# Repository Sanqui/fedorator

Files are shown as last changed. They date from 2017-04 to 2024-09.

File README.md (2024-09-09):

Fedorator
===

This is a repo containing source files for the Fedorator.

The Fedorator is a device for writing a live image of
[Fedora](http://fedoraproject.org/), the Linux distribution, onto a USB
flash drive.  It acts as a multimedia hub on Fedora booths at tech conferences
and trade shows.

**Fedorator is no longer maintained.**  If you're looking for a similar project, check out [SyncStar](https://github.com/gridhead/syncstar/)!

Mailing List
---

There is a mailing list about Fedorator: [fedorator@lists.fedoraproject.org](https://lists.fedoraproject.org/admin/lists/fedorator.lists.fedoraproject.org/)

Flock 2017 Version
---

This is the version that was built at Flock 2017.

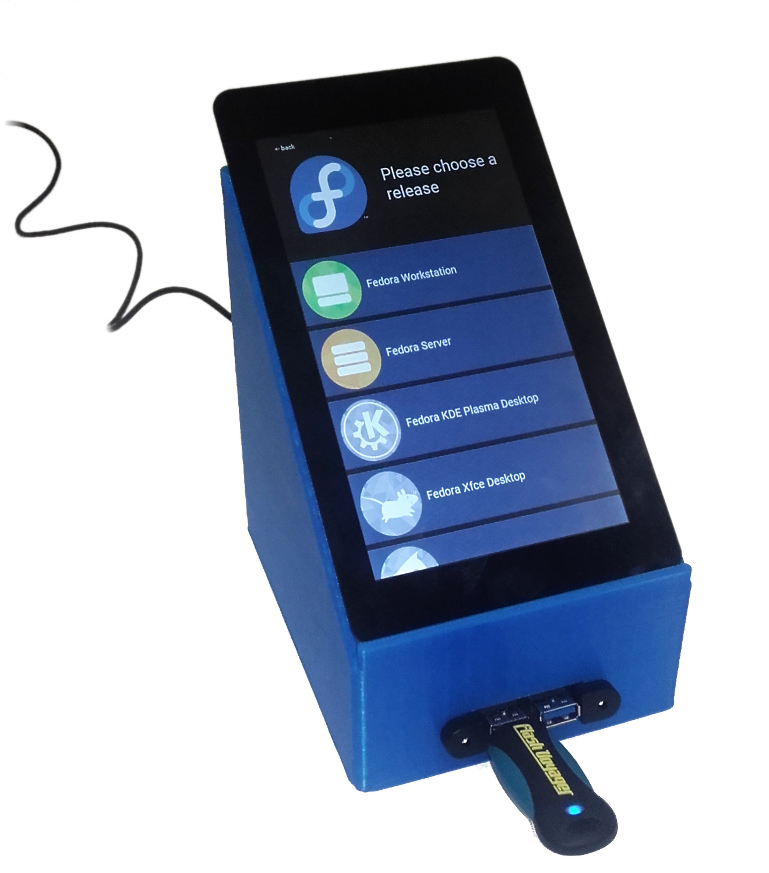
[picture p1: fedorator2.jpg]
Fedorator 2


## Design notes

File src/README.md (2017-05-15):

The fedorator source code, written in Python 3 with the Kivy framework.

The Fedora release information in data/ and img/ comes from
[Fedora Media Writer](https://github.com/MartinBriza/MediaWriter/tree/master/app/assets).

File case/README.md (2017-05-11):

`raspberry_pi_Bplus.STL` is by elsondesigns, lincensed as CC BY-SA.

Source: https://www.thingiverse.com/thing:412639

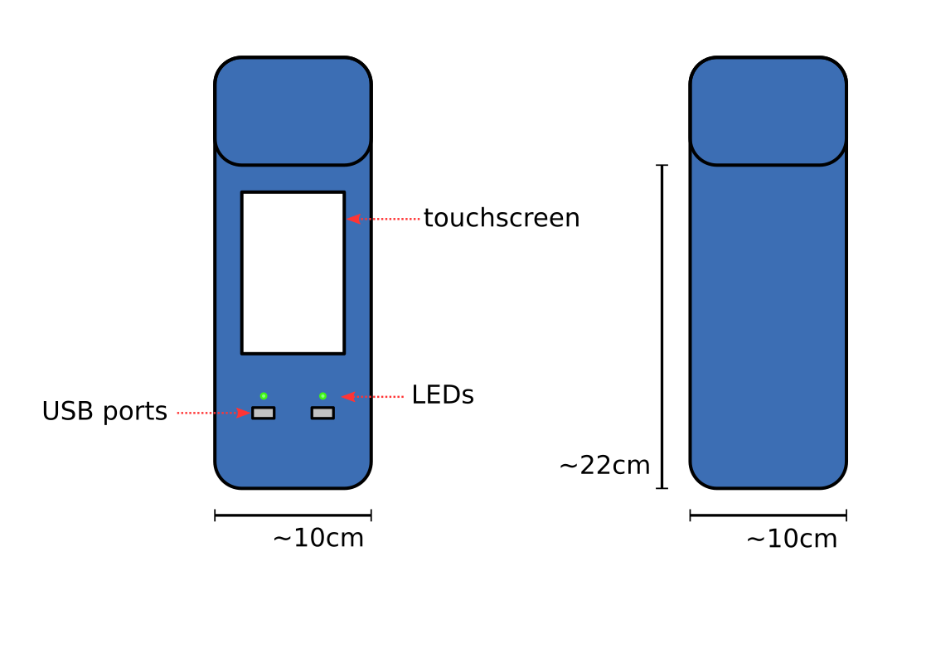
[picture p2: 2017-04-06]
concept/concept.svg.png

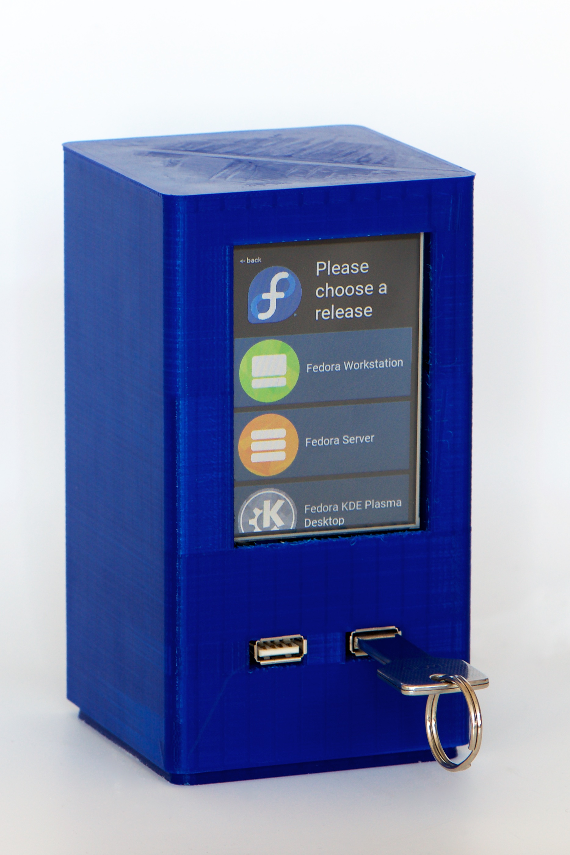
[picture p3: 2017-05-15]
fedorator-prototype.jpg

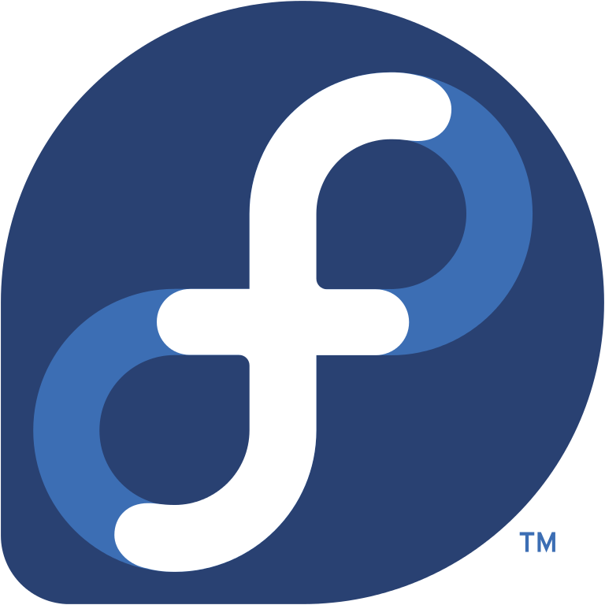
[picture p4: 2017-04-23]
src/img/fedora.png

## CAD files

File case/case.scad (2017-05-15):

HIDE_SHELL = false;
SPLIT_SHELL = true;
SPLIT_SHELL_UPSIDE_DOWN = true;
$fn=80;

TOLERANCE = 0.5;

RPI_LENGTH = 85;
RPI_WIDTH = 56;
RPI_LEFT_PORTS_WIDTH = 2.5;
RPI_HEIGHT = 5;

RPI_HEIGHT_FULL = RPI_HEIGHT + 3 + TOLERANCE;
RPI_LENGTH_FULL = RPI_LENGTH + TOLERANCE;
RPI_WIDTH_FULL = RPI_WIDTH + RPI_LEFT_PORTS_WIDTH + TOLERANCE;

RPI_WIDTH_ETHERNET = 20;
RPI_WIDTH_USB = RPI_WIDTH - RPI_WIDTH_ETHERNET;
RPI_HEIGHT_ETHERNET = 12;
RPI_HEIGHT_USB1 = 10;
RPI_LENGTH_ETHERNET = 2;
RPI_LENGTH_USB = 2;

DISPLAY_HEIGHT = 5;
DISPLAY_PIN_HEIGHT = 14;

DISPLAY_MARGIN_BOTTOM = 2.0;
DISPLAY_MARGIN_SIDE = 2.0;
DISPLAY_MARGIN_TOP = 6;

RPID_HEIGHT = RPI_HEIGHT + DISPLAY_PIN_HEIGHT + DISPLAY_HEIGHT;

USB_PORT_WIDTH = 15;
USB_PORT_HEIGHT = 8;
USB_PORT_LENGTH = 10;
USB_PORT_BOTTOM_EXTRA = 2;
USB_PORT_SIDE_EXTRA = 1;
USB_PORT_CONNECTOR_LENGTH = 40;

USB_CABLE_DIAMETER = 5;

SHELL_HEIGHT = 220;
SHELL_WIDTH = 80;
SHELL_THICKNESS = 5;

BACK_SUPPORT_LENGTH = SHELL_WIDTH/8;
CABLE_HOLE_WIDTH = 20;
USB_PORT_SUPPORT_CABLE_LENGTH = (SHELL_WIDTH - USB_PORT_CONNECTOR_LENGTH) / 2;
USB_PORT_SUPPORT_PILLAR_SIZE = USB_PORT_LENGTH;

RPI_POSITIONING = [SHELL_WIDTH / 2 - (RPI_WIDTH_FULL)/2,
                       SHELL_THICKNESS,
                       SHELL_HEIGHT/2 - RPI_LENGTH_FULL/8];

NUM_USB_PORTS = 2;
USB_PORT_Z = RPI_POSITIONING[2] / 2;

PRISM_SUPPORT_HEIGHT = RPI_POSITIONING[2]/4;

module prism(l, w, h){
    // from https://en.wikibooks.org/wiki/OpenSCAD_User_Manual/Primitive_Solids
    polyhedron(
        points=[[0,0,0], [l,0,0], [l,w,0], [0,w,0], [0,w,h], [l,w,h]],
        faces=[[0,1,2,3],[5,4,3,2],[0,4,5,1],[0,3,4],[5,2,1]]
    );
}

module rpi_with_display() {
    import("raspberry_pi_Bplus.STL", convexity=10);
    
    translate([0, RPI_LEFT_PORTS_WIDTH, RPI_HEIGHT+DISPLAY_PIN_HEIGHT])
    %cube([RPI_LENGTH, RPI_WIDTH, DISPLAY_HEIGHT]);
}

module rpid() {
    color("gray")
    translate([0,0,RPI_LENGTH])
    rotate([90,90,0])
        rpi_with_display();
}

module rounded_rect(size, radius) {
    x = size[0];
    y = size[1];
    hull() {
        for (xp = [0, 1]) {
            for (yp = [0, 1]) {
                translate([(xp*x)+(xp-0.5)*-2*(radius/2),
                           (yp*y)+(yp-0.5)*-2*(radius/2), 0])
                    circle(r=radius);
            }
        }
    }
}

module rounded_cube(size, radius, thickness) {
    x = size[0];
    y = size[1];
    z = size[2];

    linear_extrude(height=z)
        difference() {
            rounded_rect(size, radius);
            if(thickness != -1) {
                translate([thickness/2, thickness/2, 0])
                rounded_rect([size[0]-thickness, size[1]-thickness], radius);
            }
        }
}

module shell() {
    if (!HIDE_SHELL) {
        difference() {
            union() {
                // shell
                rounded_cube([SHELL_WIDTH, SHELL_WIDTH, SHELL_HEIGHT], SHELL_THICKNESS, SHELL_THICKNESS);
                
                // cap
                translate([0, 0, SHELL_HEIGHT - SHELL_THICKNESS])
                    rounded_cube([SHELL_WIDTH, SHELL_WIDTH, SHELL_THICKNESS], SHELL_THICKNESS, -1);
            }
            
            color("red")
            union() {
                // hole for display
                translate([0, -RPID_HEIGHT, 0])
                translate(RPI_POSITIONING)
                translate([DISPLAY_MARGIN_SIDE, 0, DISPLAY_MARGIN_BOTTOM])
                translate([RPI_LEFT_PORTS_WIDTH, 0, 0])
                    cube([RPI_WIDTH+TOLERANCE - DISPLAY_MARGIN_SIDE,
                          RPID_HEIGHT*2,
                          RPI_LENGTH+TOLERANCE - DISPLAY_MARGIN_TOP]);
                
                // hole for power cable in the back
                translate([SHELL_WIDTH*0.1, SHELL_WIDTH, 0])
                    cube([CABLE_HOLE_WIDTH, CABLE_HOLE_WIDTH, CABLE_HOLE_WIDTH + SHELL_THICKNESS*4]);
        
                // holes for usb ports
                for (i = [1, NUM_USB_PORTS]) {
                    translate([i*SHELL_WIDTH/(NUM_USB_PORTS+1) - USB_PORT_WIDTH/2, -USB_PORT_LENGTH, USB_PORT_Z])
                        color("blue") cube([USB_PORT_WIDTH, USB_PORT_LENGTH*2, USB_PORT_HEIGHT]);
                }
            }
        }
    }
}

module support_pillar() {
    cube([(SHELL_WIDTH - RPI_WIDTH_FULL)/2,
          RPI_POSITIONING[1] + RPID_HEIGHT,
          RPI_POSITIONING[2] + RPI_LENGTH/2]);
}

module support_prism(l, w) {
    translate([0, w, 0])
    prism(l, -w, -PRISM_SUPPORT_HEIGHT );
}

module back_support_prism(offset) {
    translate([offset, RPI_POSITIONING[1] + BACK_SUPPORT_LENGTH + RPID_HEIGHT, 0])
        prism((SHELL_WIDTH - RPI_WIDTH_FULL)/2, -BACK_SUPPORT_LENGTH, -PRISM_SUPPORT_HEIGHT );
}

module back_support(height) {
    translate([0, 0, height]) {
        translate([0, RPI_POSITIONING[1] + RPID_HEIGHT, 0])
        cube([SHELL_WIDTH,
              BACK_SUPPORT_LENGTH,
              BACK_SUPPORT_LENGTH]);

        back_support_prism(0);
        back_support_prism(RPI_POSITIONING[0] + RPI_WIDTH_FULL );
    }
}

module usb_port_support_pillar() {
    cube([USB_PORT_WIDTH + USB_PORT_SIDE_EXTRA*2, USB_PORT_SUPPORT_PILLAR_SIZE, USB_PORT_Z - USB_PORT_HEIGHT - USB_PORT_BOTTOM_EXTRA]);
}

module usb_cable(length) {
    rotate([-90, 0, 0])
    cylinder(h=length, r=USB_CABLE_DIAMETER/2);
}

module usb_port_support() {
    difference() {
        union() {
            base_support_height = USB_PORT_Z - USB_PORT_HEIGHT - USB_PORT_BOTTOM_EXTRA;
            translate([0, 0, base_support_height]) {
                cube([USB_PORT_WIDTH + USB_PORT_SIDE_EXTRA*2, USB_PORT_CONNECTOR_LENGTH + 4, USB_PORT_HEIGHT]);
                
                translate([0, USB_PORT_CONNECTOR_LENGTH + 4, 0])
                    cube([USB_PORT_WIDTH + USB_PORT_SIDE_EXTRA*2,
                        USB_PORT_SUPPORT_CABLE_LENGTH, USB_PORT_HEIGHT + USB_CABLE_DIAMETER]);
            }
            
            translate([0, 0, 0])
                usb_port_support_pillar();
            translate([0, USB_PORT_CONNECTOR_LENGTH + 4 + USB_PORT_SUPPORT_CABLE_LENGTH - USB_PORT_SUPPORT_PILLAR_SIZE, 0])
                usb_port_support_pillar();
        }
        
        translate([(USB_PORT_WIDTH + USB_PORT_SIDE_EXTRA*2)/2, 0, USB_PORT_Z + USB_PORT_BOTTOM_EXTRA])
            usb_cable(USB_PORT_CONNECTOR_LENGTH + 4 + USB_PORT_SUPPORT_CABLE_LENGTH);
    }
}

module supports() {
    // floor
    rounded_cube([SHELL_WIDTH, SHELL_WIDTH, SHELL_THICKNESS], SHELL_THICKNESS, -1);
    
    // raised border to hold the shell in
    translate([SHELL_THICKNESS, SHELL_THICKNESS, 0])
    rounded_cube([SHELL_WIDTH-SHELL_THICKNESS*2, SHELL_WIDTH-SHELL_THICKNESS*2, SHELL_THICKNESS*4], SHELL_THICKNESS*2, 4);
    translate([0, 0, 0])
        support_pillar();
    translate([RPI_POSITIONING[0] + RPI_WIDTH_FULL , 0, 0])
        support_pillar();
    
    // back support
    back_support(RPI_POSITIONING[2]);
    back_support(RPI_POSITIONING[2] + RPI_LENGTH/2);
    
    // ethernet support prism
    ethernet_prism_width = RPI_WIDTH_ETHERNET + RPI_LEFT_PORTS_WIDTH;
    translate([RPI_POSITIONING[0], 0, RPI_POSITIONING[2] - RPI_LENGTH_ETHERNET])
        support_prism(ethernet_prism_width + RPI_WIDTH_USB + TOLERANCE*2, RPID_HEIGHT - RPI_HEIGHT_ETHERNET);
    
    // usb support prism (dropped in favor of a single prism)
    /*translate([RPI_POSITIONING[0] + ethernet_prism_width, 0, RPI_POSITIONING[2] - RPI_LENGTH_ETHERNET])
        support_prism(RPI_WIDTH_USB + TOLERANCE*2, RPID_HEIGHT - RPI_HEIGHT_USB1);*/
    
    // supports for each port
    for (i = [1, NUM_USB_PORTS]) {
        translate([i*SHELL_WIDTH/(NUM_USB_PORTS+1) - USB_PORT_WIDTH/2, 0, 0])
            usb_port_support();
    }
    
    // connect pillars for extra stability
    cube([SHELL_WIDTH,
          USB_PORT_SUPPORT_PILLAR_SIZE,
          USB_PORT_Z]);
    
}

/*module shell_cap() {
    translate([SHELL_WIDTH + SHELL_THICKNESS*4, 0, 0]) {
        rounded_cube([SHELL_WIDTH, SHELL_WIDTH, SHELL_THICKNESS], 5, -1);
        translate([SHELL_THICKNESS/2, SHELL_THICKNESS/2, 0])
        rounded_cube([SHELL_WIDTH-SHELL_THICKNESS,
                      SHELL_WIDTH-SHELL_THICKNESS,
                      SHELL_THICKNESS*2], 5, -1);
    }
}*/

module split_bottom(){
    difference(){
        supports();
        shell();
    }
}

module split_top(){
    difference(){
        shell();
        supports();
    }
}

module main() {
    if (SPLIT_SHELL) {
        split_bottom();
        
        if (SPLIT_SHELL_UPSIDE_DOWN) {
            translate([SHELL_WIDTH * 2.2, 0, SHELL_HEIGHT])    
            rotate([0, 180, 0]) split_top();
        } else {
            translate([SHELL_WIDTH * 1.2, 0, 0])
            rotate([0, 0, 0]) split_top();
        }
    } else {
        supports();
        shell();
    }
}
//shell_cap();
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

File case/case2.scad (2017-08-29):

$fn=80;

TOLERANCE = 0.5;

RPI_LENGTH = 85;
RPI_WIDTH = 56;
RPI_LEFT_PORTS_WIDTH = 2.5;
RPI_HEIGHT = 5;

RPI_HEIGHT_FULL = RPI_HEIGHT + 14;
RPI_LENGTH_FULL = RPI_LENGTH + TOLERANCE;
RPI_WIDTH_FULL = RPI_WIDTH + RPI_LEFT_PORTS_WIDTH + TOLERANCE;

//DISPLAY_HEIGHT = 5;
//DISPLAY_PIN_HEIGHT = 14;

//RPI_HEIGHT_WITH_DISPLAY = RPI_HEIGHT_FULL + DISPLAY_HEIGHT;

// TODO go over these

/*USB_PORT_WIDTH = 36; // TODO
USB_PORT_HEIGHT = 12.25;
USB_PORT_INDENT = 10;
USB_PORT_ARM_WIDTH = 6;
USB_PORT_SCREW_HOLE_DISTANCE = 15;
USB_PORT_SCREW_HOLE_RADIUS = 1.5 + 0.1;*/

USB_PORT_WIDTH = 42.5; 
USB_PORT_HEIGHT = 15;
USB_PORT_INDENT = 7.5;
USB_PORT_ARM_WIDTH = 6;
USB_PORT_SCREW_HOLE_DISTANCE = 15;
USB_PORT_SCREW_HOLE_RADIUS = 1.5;
USB_PORT_USB_WIDTH = 14;
USB_PORT_USB_HEIGHT = 9;

USB_PLUG_WITH_CABLE_LENGTH = 60;
USP_PLUG_WIDTH = 30; // approx.
USB_PLUG_HEIGHT = 5; // approx.


RPI_DISPLAY_BOARD_DISTANCE = 8;
DISPLAY_BOARD_HEIGHT = 1;
DISPLAY_BOARD_LENGTH = 66;

// values from https://www.raspberrypi.org/documentation/hardware/display/7InchDisplayDrawing-14092015.pdf
DISPLAY_BASE_LENGTH = 164.9;
DISPLAY_BASE_WIDTH = 100.6;
DISPLAY_BASE_THICKNESS = 2.5;
DISPLAY_BASE_OFF_BOARD_X = 48.45; 
DISPLAY_BASE_OFF_BOARD_Y = DISPLAY_BASE_WIDTH - RPI_WIDTH - 20.8; 

DISPLAY_LENGTH = 192.96;
DISPLAY_WIDTH = 110.76;
DISPLAY_THICKNESS = 1.4;

DISPLAY_ANCHOR_HEIGHT = 2;

DISPLAY_X_MISPLACEMENT_INNER = 5;
DISPLAY_X_MISPLACEMENT = -6.63 + DISPLAY_X_MISPLACEMENT_INNER;

SHELL_HEIGHT1 = 50;
SHELL_HEIGHT2 = 150 - SHELL_HEIGHT1;
SHELL_HEIGHT = SHELL_HEIGHT1 + SHELL_HEIGHT2;
SHELL_WIDTH = DISPLAY_BASE_WIDTH + 0.5 + DISPLAY_X_MISPLACEMENT_INNER;
SHELL_LENGTH = 135;
SHELL_THICKNESS = 4;

SHELL_ANGLE = -atan(SHELL_LENGTH/SHELL_HEIGHT2);
SHELL_TOP_LENGTH = sqrt(pow(SHELL_LENGTH, 2)+pow(SHELL_HEIGHT2,2));

/*RPI_POSITIONING = [(SHELL_WIDTH) / 2 - (RPI_WIDTH_FULL)/2,
                       0,
                       SHELL_TOP_LENGTH/6];
                       */
SHELL_TOP_TO_DISPLAY_BOTTOM = RPI_LENGTH * 1.2;
SHELL_BOTTOM_TO_DISPLAY = SHELL_TOP_LENGTH - SHELL_TOP_TO_DISPLAY_BOTTOM;
DISPLAY_POSITIONING = [(SHELL_WIDTH) / 2 - (RPI_WIDTH)/2,
                       0,
                       SHELL_TOP_LENGTH - SHELL_TOP_TO_DISPLAY_BOTTOM];

RUBBER_FOOT_DIAMETER = 17.5;
RUBBER_FOOT_HEIGHT = 9 - 0.5;


RUBBER_FEET_X1 = 0;
RUBBER_FEET_X2 = SHELL_WIDTH - RUBBER_FOOT_DIAMETER;
RUBBER_FEET_Y1 = 0;
RUBBER_FEET_Y2 = -SHELL_THICKNESS + SHELL_LENGTH/2;
RUBBER_FEET_Y3 = SHELL_LENGTH - RUBBER_FOOT_DIAMETER - SHELL_THICKNESS/2;

USB_PORT_X1 = SHELL_WIDTH/2-USB_PORT_WIDTH - SHELL_THICKNESS*0;
USB_PORT_X2 = SHELL_WIDTH/2 + SHELL_THICKNESS*0;
USB_PORT_Z = SHELL_HEIGHT1/2-USB_PORT_HEIGHT;

module prism(l, w, h){
    // from https://en.wikibooks.org/wiki/OpenSCAD_User_Manual/Primitive_Solids
    polyhedron(
        points=[[0,0,0], [l,0,0], [l,w,0], [0,w,0], [0,w,h], [l,w,h]],
        faces=[[0,1,2,3],[5,4,3,2],[0,4,5,1],[0,3,4],[5,2,1]]
    );
}

/*module rpi_with_display_small() {
    // small display
    import("raspberry_pi_Bplus.STL", convexity=10);
    
    translate([0, RPI_LEFT_PORTS_WIDTH, RPI_HEIGHT+DISPLAY_PIN_HEIGHT])
        cube([RPI_LENGTH, RPI_WIDTH, DISPLAY_HEIGHT]);
    
    // double usb plug
    translate([RPI_LENGTH-USB_PORT_LENGTH, RPI_WIDTH-USP_PLUG_WIDTH, 13])
        cube([USB_PLUG_WITH_CABLE_LENGTH, USP_PLUG_WIDTH, USB_PLUG_HEIGHT]);
}*/


module display_anchor() {
    translate([0, 0, DISPLAY_ANCHOR_HEIGHT*2])
    cube([10, 5, DISPLAY_ANCHOR_HEIGHT], center=true);
}

module rpi_with_display() {
    translate([27, 47, 0]) // XXX
    translate([RPI_WIDTH_FULL, RPI_LENGTH, -RPI_DISPLAY_BOARD_DISTANCE])
    rotate([0, 180, 90]) {
        color("gray")
        import("raspberry_pi_Bplus.STL", convexity=10);
        
        // double usb plug
        translate([RPI_LENGTH-USB_PORT_LENGTH, RPI_WIDTH-USP_PLUG_WIDTH, 13])
            cube([USB_PLUG_WITH_CABLE_LENGTH, USP_PLUG_WIDTH, USB_PLUG_HEIGHT]);
        
        translate([0, RPI_LEFT_PORTS_WIDTH, -RPI_DISPLAY_BOARD_DISTANCE])
        {
         display();
        }
    }
}


module display() {
    cube([DISPLAY_BOARD_LENGTH, RPI_WIDTH, DISPLAY_BOARD_HEIGHT]);
        translate([-DISPLAY_BASE_OFF_BOARD_X, -DISPLAY_BASE_OFF_BOARD_Y, -DISPLAY_BASE_THICKNESS - 2])
        {
            cube([DISPLAY_BASE_LENGTH, DISPLAY_BASE_WIDTH, DISPLAY_BASE_THICKNESS]);
            
            
            x1 = 20.0;
            x2 = 20.0 + 126.2;
            y1 = DISPLAY_BASE_WIDTH + 6.63 - 21.58;
            y2 = DISPLAY_BASE_WIDTH + 6.63 - 21.58 - 65.65;
            
            translate([x1, y1, -0.3])
                display_anchor();
            translate([x2, y1, -0.3])
                display_anchor();
            translate([x1, y2, -0.3])
                display_anchor();
            translate([x2, y2, -0.3])
                display_anchor();
            
            translate([-11.89, -(DISPLAY_WIDTH - DISPLAY_BASE_WIDTH - 6.63), - 0.3])
            cube([DISPLAY_LENGTH, DISPLAY_WIDTH, DISPLAY_THICKNESS]);
        }
}

module rpid() {
    color("gray")
    translate([0,0,RPI_LENGTH])
    rotate([90,90,0])
        rpi_with_display();
}


module rounded_rect(size, radius) {
    x = size[0];
    y = size[1];
    hull() {
        for (xp = [0, 1]) {
            for (yp = [0, 1]) {
                translate([(xp*x)+(xp-0.5)*-2*(radius/2),
                           (yp*y)+(yp-0.5)*-2*(radius/2), 0])
                    circle(r=radius);
            }
        }
    }
}


module rounded_cube(size, radius, thickness) {
    x = size[0];
    y = size[1];
    z = size[2];

    linear_extrude(height=z)
        difference() {
            rounded_rect(size, radius);
            if(thickness != -1) {
                translate([thickness/2, thickness/2, 0])
                rounded_rect([size[0]-thickness, size[1]-thickness], radius);
            }
        }
}

module rpi_support_prism() {
    w = RPI_WIDTH/4;
    h = tan(90+SHELL_ANGLE)*RPI_LENGTH-RPI_HEIGHT;
    l = sqrt(pow(RPI_LENGTH, 2) - pow(h, 2));
    prism(w,
        l,
        h);
    
    translate([0, 0, -SHELL_HEIGHT1])
        cube([w, l/5, SHELL_HEIGHT1]);
    
    translate([0, l - l/5, -SHELL_HEIGHT1])
        cube([w, l/5, SHELL_HEIGHT1]);
}

module rpi_support() {
    rpi_support_prism();
    translate([RPI_WIDTH - RPI_WIDTH/4, 0, 0])
        rpi_support_prism();
}

ANCHOR_SUPPORT_SIZE = 8;
ANCHOR_SUPPORT_DEPTH = 5.5;
ANCHOR_SUPPORT_SPOT_DEPTH = 5.5;
ANCHOR_SUPPORT_OFF_TOP = DISPLAY_ANCHOR_HEIGHT+4.5;

ANCHOR_SCREW_RADIUS = 1.5 + 0.1;

module shell_anchor_support() {
    translate([0, 0, -ANCHOR_SUPPORT_OFF_TOP - ANCHOR_SUPPORT_DEPTH])
    cube([SHELL_WIDTH + SHELL_THICKNESS, ANCHOR_SUPPORT_SIZE, ANCHOR_SUPPORT_DEPTH]);
}
module shell_anchor_extension() {
    translate([-ANCHOR_SUPPORT_SIZE/2, -ANCHOR_SUPPORT_SIZE/2, -ANCHOR_SUPPORT_OFF_TOP-ANCHOR_SUPPORT_SPOT_DEPTH])
    cube([ANCHOR_SUPPORT_SIZE, ANCHOR_SUPPORT_SIZE, ANCHOR_SUPPORT_SPOT_DEPTH]);
}

module shell_anchor_hole() {
    translate([0, 0, -ANCHOR_SUPPORT_OFF_TOP-ANCHOR_SUPPORT_SPOT_DEPTH])
    cylinder(h=ANCHOR_SUPPORT_SPOT_DEPTH, r=ANCHOR_SCREW_RADIUS);
}

// XXX TODO calculate this properly
ANCHOR_SUPPORT_PRISM_WIDTH = ANCHOR_SUPPORT_SIZE * 1.22;

module shell_anchor_prism(length, mirror=false) {
    height = 30;
    translate([0, mirror ? ANCHOR_SUPPORT_PRISM_WIDTH : 0, -height])
    rotate([90, 0, mirror ? 270 : 90])
        prism(ANCHOR_SUPPORT_PRISM_WIDTH, height, length-1);
}

USB_PORT_INDENT_PILLAR_HEIGHT = USB_PORT_Z + USB_PORT_HEIGHT*1;

module usb_port_indent_pillar(right=0) {
    translate([0, -SHELL_THICKNESS, -USB_PORT_Z])
        cube([USB_PORT_ARM_WIDTH, USB_PORT_INDENT + SHELL_THICKNESS*2, USB_PORT_INDENT_PILLAR_HEIGHT]);
    
    translate([-SHELL_THICKNESS/2 + right*SHELL_THICKNESS*2, -SHELL_THICKNESS, -USB_PORT_Z])
        cube([SHELL_THICKNESS/2, USB_PORT_INDENT + SHELL_THICKNESS*2, USB_PORT_INDENT_PILLAR_HEIGHT]);
}

module usb_port_indent(right=0) {
    if(right==0)
        usb_port_indent_pillar(right=0);
    
    if(right==1)
        translate([USB_PORT_WIDTH-USB_PORT_ARM_WIDTH, 0])
            usb_port_indent_pillar(right=1);
}

module usb_port_screw_hole() {
    rotate([90, 0, 0])
        cylinder(h=ANCHOR_SUPPORT_SPOT_DEPTH, r=USB_PORT_SCREW_HOLE_RADIUS);
}
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

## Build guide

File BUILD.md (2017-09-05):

# Building a Fedorator

The Fedorator was designed as open hardware made from readily available
components.  This means anybody from all around the world can build one,
should they wish.

## Components

The Fedorator makes use of the following components.

 * Raspberry Pi 3 Model B
 * MicroSD card (at least 16 GB recommended)
 * [Raspberry Pi touch display](https://www.raspberrypi.org/products/raspberry-pi-touch-display/)
 * 2x [USB panel mount](https://www.amazon.com/StarTech-com-Panel-Mount-USB-Cable/dp/B002M8RVKA)
 * Micro-USB powering cable (at least 2A, e.g. [from CanaKit](https://www.canakit.com/raspberry-pi-adapter-power-supply-2-5a.html))
 * 8x M3 screw
 * 4x GF2 rubber foot

You will need to get ahold of these components yourself.  As a tip, there
are many resellers of the Raspberry Pi around the world listed
[here](http://farnell.com/raspberrypi-consumer/approved-retailers.php), or
you can simply make an Internet search in your local area.

In order to make the case, a 3D printer is required.

## Software

The Fedorator software runs on both the [Raspbian](https://www.raspberrypi.org/downloads/raspbian/)
distribution, as well as [Fedora](https://arm.fedoraproject.org/).  Sadly, the official Raspberry Pi screen is not
yet supported Fedora; this situation should change soon, though, however.

In order to set up a Fedorator environment, follow the following instruction.

Install and boot into your operating system.

Log in and follow these instructions to set up the Fedorator software.

    $  # First, install requirements
    $  # On Fedora
    $ sudo dnf install git python3-virtualenv redhat-rpm-config mesa-libGL-devel
    
    $  # On Raspbian
    $ sudo apt-get install git python3-virtualenv cython3 libsdl1.2-dev
    $  # if testing with a DE
    $ sudo apt-get build-dep python3-pygame
     
    $  # Clone this repository into the home directory
    $ git clone https://github.com/Sanqui/fedorator
    $ cd fedorator/src
     
    $  # Set up the virtualenv
    $ python3 -m virtualenv --python=python3 env
    $ source env/bin/activate
    $ pip install cython
    $ pip install -r requirements.txt
     
    $ # if testing with a DE
    $ pip install pygame

To run the software now, simply do

    $ python3 main.py
    
If an Xorg session is present, the software is better tested with `./test.sh`,
which sets the correct screen resolution.

If the software is working, we can download some image files, or .isos, which
will then be made available for writing to USB flash drives.

`releases.py` is a simple script to download the most common Fedora images.
By default, it attempts to download 10 images.  You may set the number of
desired images by passing it as the argument.  Keep in mind that each image
is about 1.5 GiB large.  

    $ python3 releases.py

The Fedorator software needs to run as root and should start on system boot
and run indefinedly.  On Raspian, this can be accomplished by adding the
following to `/etc/rc.local`:
    
    cd /home/pi/fedorator/src
    source env/bin/activate
    python3 main.py &

## Hardware-specific setup

The Fedorator is designed to have the screen positioned vertically.  Displays will
require some sort of manual configuration in order to rotate.  For example, on
Raspbian, a common way to rotate the display is by appending `display_rotate=1` to
`/boot/config.txt`.

In case the touch screen coordinates are inverted, this can be patched in kivy by
editing the config in `~/.kivy/config.ini` (as well as `/root/.kivy.config.ini`).

TODO: Provide the exact instructions for this.

## Assembly

The Fedorator requires manual assembly.

### Printing the case

The case can be found in `case/case.scad`.  It may be edited and exported
with OpenSCAD.  As a parametric object, it's possible to adjust the values to
your liking, however keep in mind that a lot of parts are meticulously aligned.

The case is best printed from the PLA material.  A dark blue filament color,
e.g. [True Blue](https://www.lulzbot.com/store/filament/polylite-pla?product_filament_colors=192), is recommended.

Make sure supports are in use for the two arms suppporting the display.

## Setup

Photographic instructions are coming soon.

 1. Remove all supports from the 3D printed case.
 2. Insert the rubber legs and screw them in using 3M screws.
 3. Insert the USB panels and fasten the screws.
 4. Take the Raspberry Pi and connect it to the display, by first tightening the screws, then connecting the display using the flex cable.  Use the jumper cables to connect the first and third Raspberry Pi pin to the first and fifth display pin.
 5. Pass the MicroUSB cable through the round hole at the back side of the case.
 6. Connect the MicroUSB cable to the Raspberry Pi.
 7. Connect the USB panel mounts to the Rasberry Pi.
 8. Lay down the Raspberry Pi and display on top of the case.
 9. Fasten all four screws connecting the screen.
 10. Insert the MicroSD card containing the system in the Raspberry Pi

Now the Fedorator should be ready to plug in and function.

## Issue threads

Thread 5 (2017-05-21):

Next iteration of the case

Sanqui, 2017-05-21:
* Lay back the screen
* Fixate screen and USB ports

hopparz, 2017-05-22:
Is it possible to add universal usb hub with sd card slots?

Closed 2017-08-29.

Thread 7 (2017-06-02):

Photobooth camera support and monopod/tripod stand screwhole support option in case design

hopparz, 2017-06-02:
If you have a camera hole in the box design it would be amazing to add photobooth and twitter/social channel combo option. We had earlier photobooth code for the Pi camera, and code also what we used in earlier Fudcon, Flock times - implementing would be a nice addon to the Fedorator.

Also we gonna need monopod/tripod screw mounting hole to the box, so we can easily make group pictures with the Fedorator.

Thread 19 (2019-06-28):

Can't install requirements.txt on the latest Raspbian (Buster)

RheaAyase, 2019-06-28:
`kivy` needs a version bump to 1.10.0 (at least?) to fix the first issue where it fails to resolve dependencies which was fixed in 1.10.0

There may be other kivy issues that I've not hit yet.

2nd issue (which I failed to figure out in the time I had for it) is that cython fails to install for some reason that I can't even tell cuz it spits out spam longer than my console scrollback :D

```
  Building wheel for Cython (setup.py) ... error
  ERROR: Complete output from command /home/rhea/fedorator/src/env/bin/python3 -u -c 'import setuptools, tokenize;__file__='"'"'/tmp/pip-install-n8gtwz4u/Cython/setup.py'"'"';f=getattr(tokenize, '"'"'open'"'"', open)(__file__);code=f.read().replace('"'"'\r\n'"'"', '"'"'\n'"'"');f.close();exec(compile(code, __file__, '"'"'exec'"'"'))' bdist_wheel -d /tmp/pip-wheel-hwdsmca3 --python-tag cp37:                                                                                   
  ERROR: Unable to find pgen, not compiling formal grammar.
```
<snip>
```
  running build_ext                                                                                              
  cythoning /tmp/pip-install-n8gtwz4u/Cython/Cython/Plex/Scanners.py to /tmp/pip-install-n8gtwz4u/Cython/Cython/Plex/Scanners.c                                                                                                           
  Traceback (most recent call last):                                                                             
    File "<string>", line 1, in <module>                                                                         
    File "/tmp/pip-install-n8gtwz4u/Cython/setup.py", line 336, in <module>                                      
      **setup_args                                                                                               
    File "/home/rhea/fedorator/src/env/lib/python3.7/site-packages/setuptools/__init__.py", line 145, in setup   
      return distutils.core.setup(**attrs) 

<snip>

  SyntaxError: invalid syntax
  ----------------------------------------
  ERROR: Failed building wheel for Cython
```
<snip>
```
  Rolling back uninstall of Cython

ERROR: Command "/home/rhea/fedorator/src/env/bin/python3 -u -c 'import setuptools, tokenize;__file__='"'"'/tmp/pip-install-n8gtwz4u/Cython/setup.py'"'"';f=getattr(tokenize, '"'"'open'"'"', open)(__file__);code=f.read().replace('"'"'\r\n'"'"', '"'"'\n'"'"');f.close();exec(compile(code, __file__, '"'"'exec'"'"'))' install --record /tmp/pip-record-9uoiyke2/install-record.txt --single-version-externally-managed --compile --install-headers /home/rhea/fedorator/src/env/include/site/python3.7/Cython" failed with error code 1 in /tmp/pip-install-n8gtwz4u/Cython/
```

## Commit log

2017-05-01 Implement ImageButton for back button
2017-05-07 Release list is buttons
2017-05-07 Wrap text properly on release buttons
2017-05-10 Add a flash button with a mock progress bar
2017-05-10 Add dummy device and functional writing
2017-05-11 case: Add first go at the case
    [case.scad]
2017-05-11 case: Add bottom and back support
    [case.scad]
2017-05-11 case: Add USB slot without supports yet
    Also fix dimensions due to rounded corners
    [case.scad]
2017-05-11 case: Add support for USB connector and cable
    [case.scad]
2017-05-11 case: Support for multiple USB slots
    [case.scad]
2017-05-11 case: split shell
    [case.scad]
2017-05-11 case: Split shell and push screen in with margins
    [case.scad]
2017-05-11 case: Add a raised border
    [case.scad]
2017-05-11 case: Render split shell upside down
    Also change shell height to 157.
    This is the final version which is being printed.
    [case.scad]
2017-05-14 Assembly section
    [case.scad]
2017-05-15 case: Make the power cable hole reach to the ground
    [case.scad]
2017-05-15 Add prototype photo to README
2017-06-09 Add Fedora 26 Alpha, handling of a stalled process.
2017-07-30 Basic second case, no supports yet
    [case2.scad]
2017-08-16 case2: some progress
    [case2.scad]
2017-08-16 case2: support for screw holes
    [case2.scad]
2017-08-16 case2: Hole for screws for the USB slot
    [case2.scad]
2017-08-16 case2: add rubber feet indents
    [case2.scad]
2017-08-16 case2: Add rubber feet and two usb slots
    [case2.scad]
2017-08-16 case2: prism supports for anchor arms
    [case2.scad]
2017-08-29 Smooth out a little bit
    * Change various dimensions
    * Easier testing
    * Remove version select
    [case2.scad]
2017-08-29 Exit on ESC
